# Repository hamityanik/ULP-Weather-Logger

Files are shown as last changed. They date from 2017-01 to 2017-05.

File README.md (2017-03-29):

# ULP Weather Logger
Yet another ESP8266 (ESP-03) based ultra low power wi-fi weather logger with 4 sensors

[Follow me on Twitter (@hamityanik)](https://twitter.com/hamityanik) (@hamityanik)

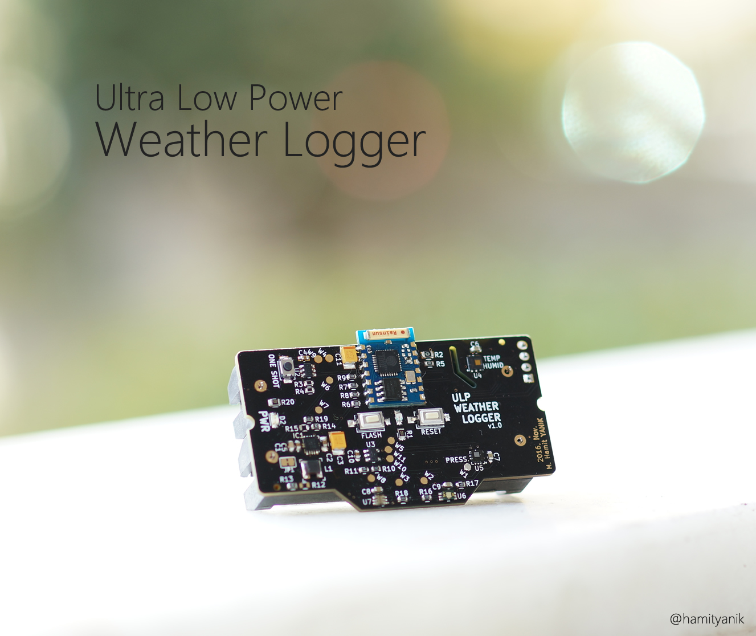
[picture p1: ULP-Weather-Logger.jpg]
Ultra Low Power Weather Logger


> **Features**

> - Working with two **AA** battery
> - Ultra low power consumption
> - **4 sensors and 6 measurements:**
>  - HDC1080 - Temperature & Humidity
>  - LPS25HB - Pressure
>  - VEML6070 - Ultraviolet Index
>  - TSL2561 - Ambient & Infrared
> - Built-in 3.3v Boost Converter
> - TPL5111 System Timer (20 mins update interval, can be customized via resistors)
> - Battery voltage monitor
> - UART port for programming & debugging 

## Blynk Integration
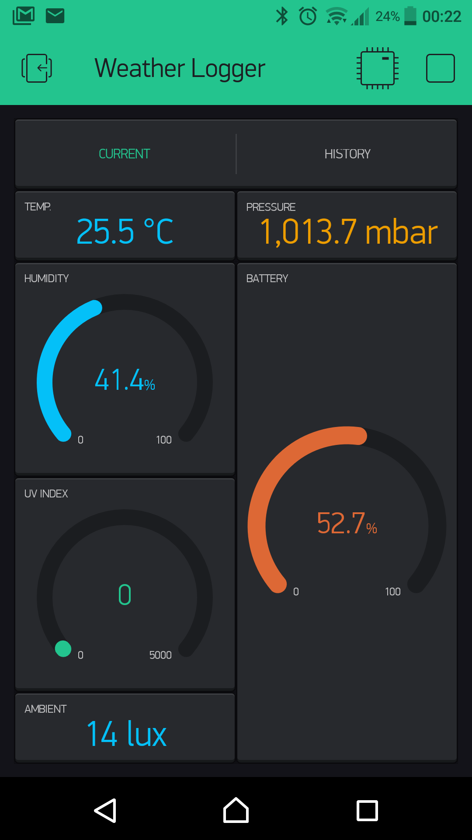
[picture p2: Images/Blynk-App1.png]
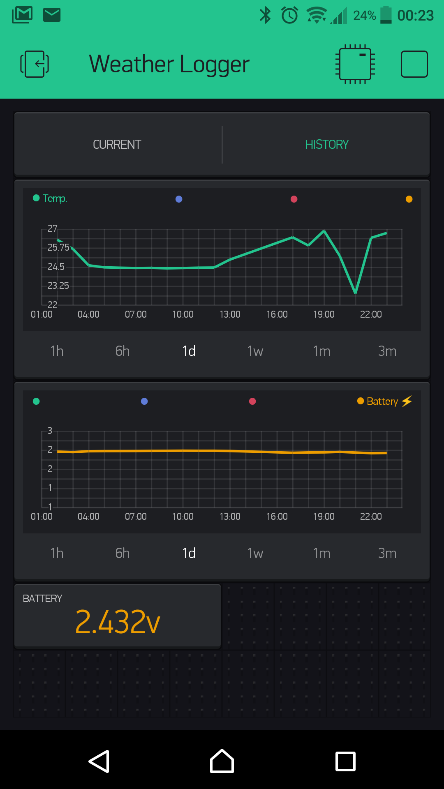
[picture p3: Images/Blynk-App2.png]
 

## How can you buy one?


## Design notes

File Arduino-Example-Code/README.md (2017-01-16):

# Example Arduino Code
-----

In **libraries** folder, there are optimized versions of sensor libraries. Use with caution.

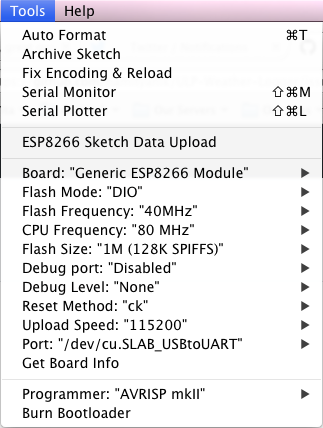
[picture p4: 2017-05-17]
Images/arduino_config.png

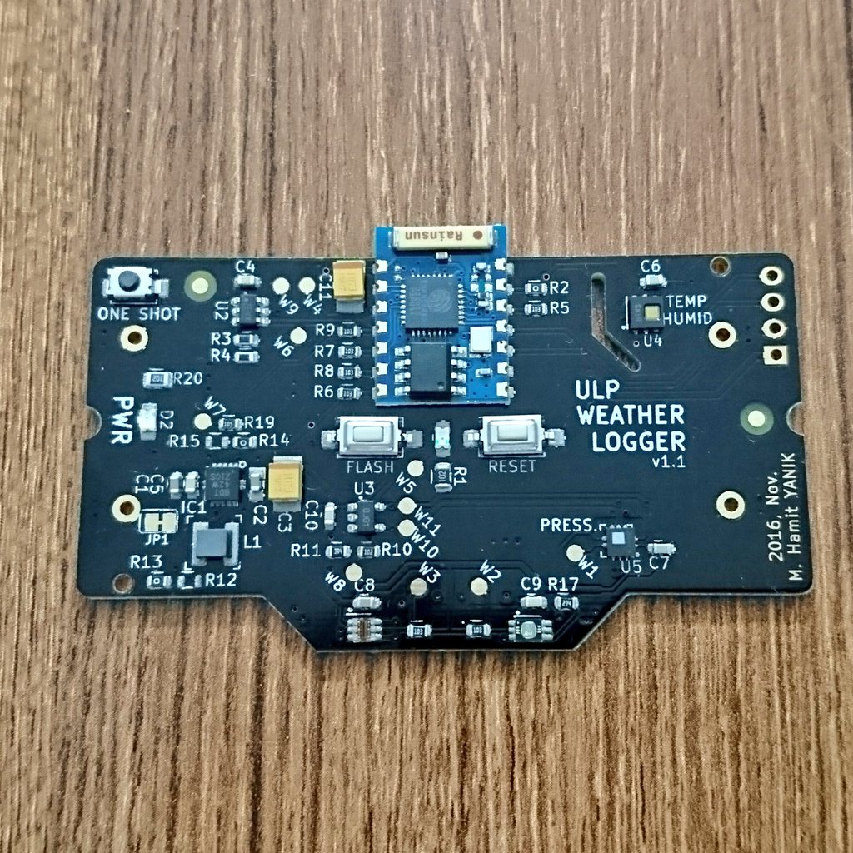
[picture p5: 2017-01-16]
Images/IMG_-c0ex6u.jpg

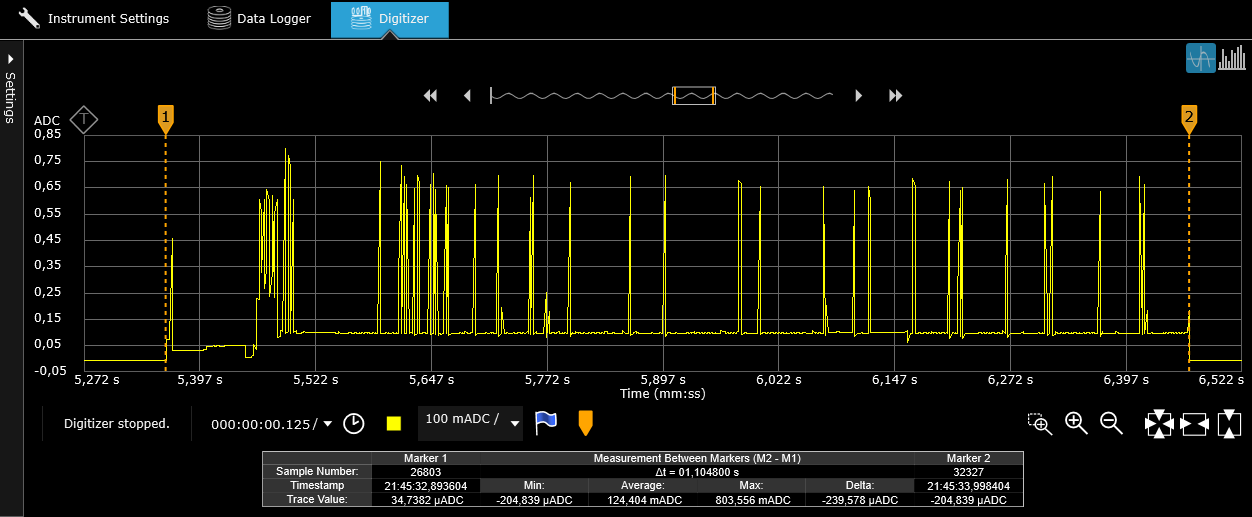
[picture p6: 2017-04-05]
Images/@2.5v.png

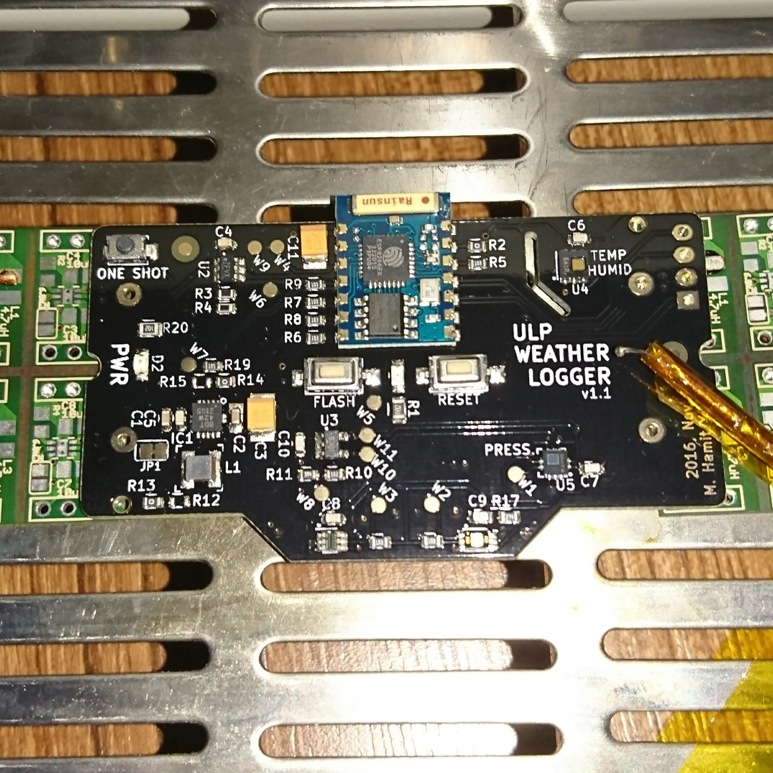
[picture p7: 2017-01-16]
Images/IMG_962an6.jpg

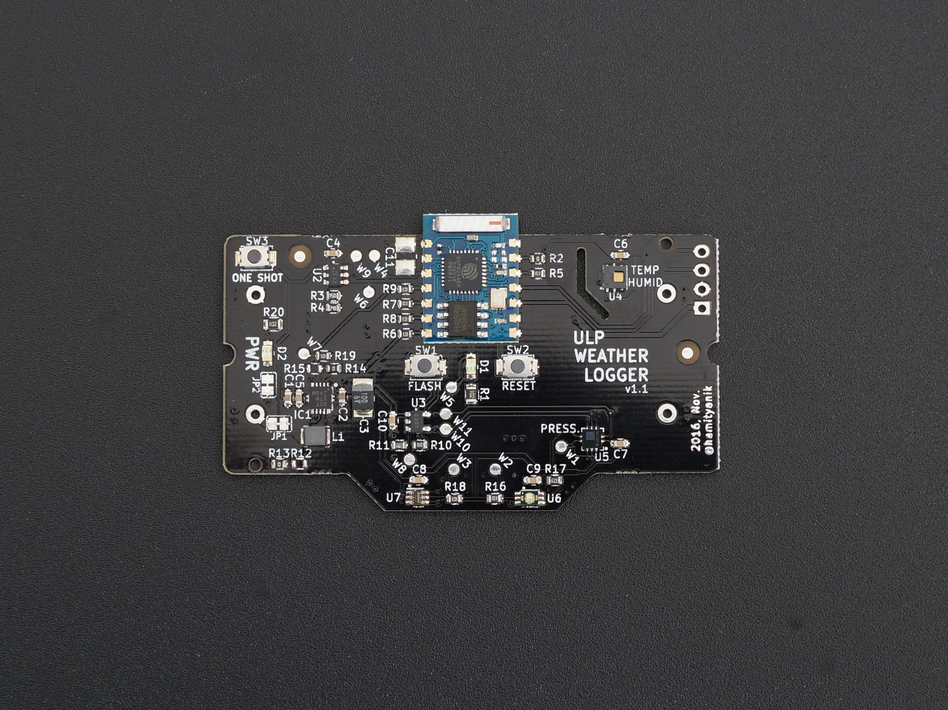
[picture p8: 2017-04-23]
Images/WL 1.jpg

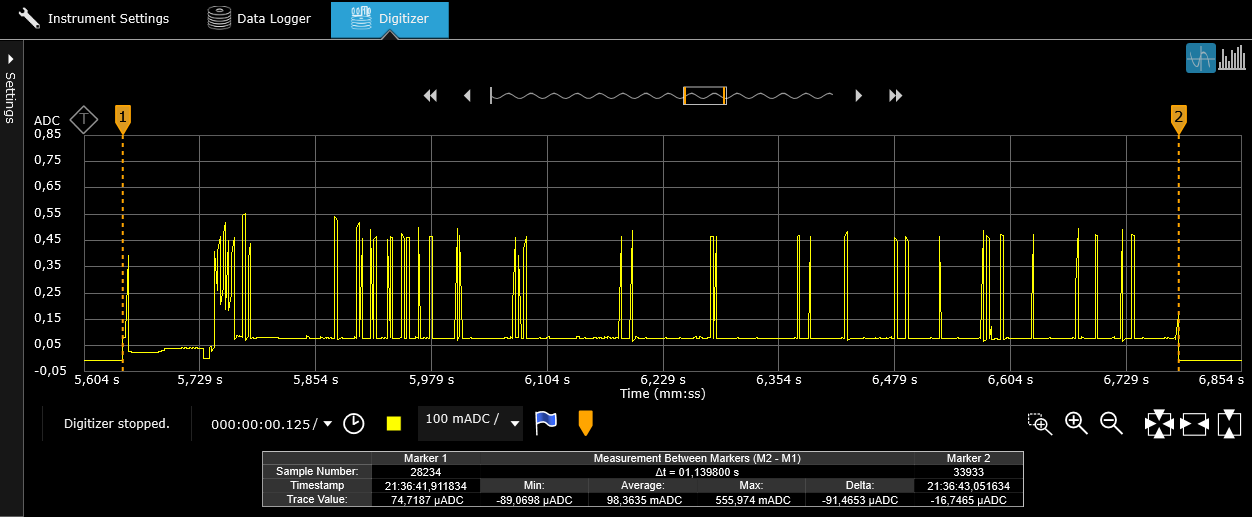
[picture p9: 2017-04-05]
Images/@3v.png

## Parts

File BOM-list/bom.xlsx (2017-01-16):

 |  |  |  |  | Board Qty: | 100
 |  |  |  |  | Total Cost: | $1607.98 |  |  |  | $1344.93 |  |  |  |  |  | $3472.30 |  |  |  |  |  | $1281.30 |  |  |  |  |  | $690.00 |  |  |  |  |  | $721.47 |  |  |  |  |  | $0.00
 |  |  |  |  | Unit Cost: | $16.08
Global Part Info |  |  |  |  |  |  | Digi-Key |  |  |  |  |  | Farnell |  |  |  |  |  | Mouser |  |  |  |  |  | Newark |  |  |  |  |  | Rs Components |  |  |  |  |  | Local
Refs | Value | Manf | Manf# | Qty | Unit$ | Ext$ | Avail | Purch | Unit$ | Ext$ | Cat# | Doc | Avail | Purch | Unit$ | Ext$ | Cat# | Doc | Avail | Purch | Unit$ | Ext$ | Cat# | Doc | Avail | Purch | Unit$ | Ext$ | Cat# | Doc | Avail | Purch | Unit$ | Ext$ | Cat# | Doc | Avail | Purch | Unit$ | Ext$ | Cat# | Doc
R10 | 1k | Yageo | RC0603FR-071KL | 100 | $0.003 | $0.30 | 9492159 |  | $0.01 | $0.52 | 311-1.00KHRCT-ND | Link (http://www.digikey.com/product-detail/en/yageo/RC0603FR-071KL/311-1.00KHRCT-ND/729790) | 160280 |  | $0.01 | $0.83 | 9238484 | Link (http://it.farnell.com/yageo-phycomp/rc0603fr-071kl/res-film-spesso-1k-1-0-1w-0603/dp/9238484) | 599743 |  | $0.003 | $0.30 | 603-RC0603FR-071KL | Link (http://www.mouser.com/Search/Refine.aspx?Keyword=RC0603FR-071KL%20Yageo) | 4140 |  | $0.01 | $0.60 | 68R0042 | Link (http://www.newark.com/yageo/rc0603fr-071kl/res-thick-film-1k-1-0-1w-0603/dp/68R0042)
D2 | PWR | Lite-On Inc. | LTST-C171KRKT | 100 | $0.12 | $11.83 | 143608 |  | $0.12 | $11.83 | 160-1427-1-ND | Link (http://www.digikey.com/product-detail/en/lite-on-inc/LTST-C171KRKT/160-1427-1-ND/386800) |  |  |  |  |  |  |  |  |  |  |  |  |  |  |  |  |  |  | 250 |  | $0.17 | $16.94 | 692-0941 | Link (http://it.rs-online.com/web/c/?searchTerm=LTST-C171KRKT%20Lite-On%20Inc.)
U6 | VEML6070 | Vishay Semiconductor Opto Division | VEML6070 | 100 | $1.25 | $125.00 | 3205 |  | $1.50 | $149.60 | VEML6070CT-ND | Link (http://www.digikey.com/product-detail/en/vishay-semiconductor-opto-division/VEML6070/VEML6070CT-ND/5171286) | 3617 |  | $1.43 | $142.94 | 2504137 | Link (http://it.farnell.com/vishay/veml6070/sensore-raggi-uv-5-5v-16bit-digitale/dp/2504137) |  |  |  |  |  |  | 1493 |  | $1.25 | $125.00 | 41Y9254 | Link (http://www.newark.com/vishay/veml6070/uv-light-sensor-355nm-i2c/dp/41Y9254)
L1 | 6.8uH | Murata Electronics | LQH32PN6R8NN0L | 100 | $0.24 | $23.51 | 5376 |  | $0.26 | $25.51 | 490-5339-1-ND | Link (http://www.digikey.com/product-detail/en/murata-electronics-north-america/LQH32PN6R8NN0L/490-5339-1-ND/2092212) |  |  |  |  |  |  | 1476 |  | $0.24 | $23.60 | 81-LQH32PN6R8NN0L | Link (http://www.mouser.com/Search/Refine.aspx?Keyword=LQH32PN6R8NN0L%20Murata%20Electronics) |  |  |  |  |  |  | 1660 |  | $0.24 | $23.51 | 786-6908 | Link (http://it.rs-online.com/web/c/?searchTerm=LQH32PN6R8NN0L%20Murata%20Electronics)
R3 | 140k | Yageo | RC0603FR-07140KL | 100 | $0.003 | $0.30 | 190971 |  | $0.01 | $0.52 | 311-140KHRCT-ND | Link (http://www.digikey.com/product-detail/en/yageo/RC0603FR-07140KL/311-140KHRCT-ND/729894) |  |  |  |  |  |  | 24121 |  | $0.003 | $0.30 | 603-RC0603FR-07140KL | Link (http://www.mouser.com/Search/Refine.aspx?Keyword=RC0603FR-07140KL%20Yageo) |  |  |  |  |  | Link (http://www.newark.com/webapp/wcs/stores/servlet/Search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)
R4 | 174k | Yageo | RC0603FR-07174KL | 100 | $0.003 | $0.30 | 171006 |  | $0.01 | $0.52 | 311-174KHRCT-ND | Link (http://www.digikey.com/product-detail/en/yageo/RC0603FR-07174KL/311-174KHRCT-ND/729932) |  |  |  |  |  |  | 61300 |  | $0.003 | $0.30 | 603-RC0603FR-07174KL | Link (http://www.mouser.com/Search/Refine.aspx?Keyword=RC0603FR-07174KL%20Yageo) |  |  |  |  |  | Link (http://www.newark.com/webapp/wcs/stores/servlet/Search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)
SW3 | M_DRV | C&K | PTS820 J15M SMTR LFS | 100 | $0.35 | $35.20 | 76752 |  | $0.35 | $35.20 | CKN10506CT-ND | Link (http://www.digikey.com/product-detail/en/c-k/PTS820-J15M-SMTR-LFS/CKN10506CT-ND/4176681) |  |  |  |  |  |  |  |  |  |  |  | Link (http://www.mouser.com/ProductDetail/CK-Components/PTS820-J15M-SMTR-LFS/)
BT1,BT2 | Battery | Keystone Electronics | 1015 | 200 | $1.72 | $344.00 |  |  |  |  |  |  |  |  |  |  |  |  | 121 |  | $1.72 | $344.00 | 534-1015 | Link (http://www.mouser.com/Search/Refine.aspx?Keyword=1015%20Keystone%20Electronics)
SW1,SW2 | FLASH,RESET | C&K | RS-282G05A3-SM RT | 200 | $0.55 | $110.00 | 52850 |  | $0.55 | $110.00 | CKN10384CT-ND | Link (http://www.digikey.com/product-detail/en/c-k/RS-282G05A3-SM-RT/CKN10384CT-ND/2747203) |  |  |  |  |  |  | 6708 |  | $0.55 | $110.00 | 611-RS-282G05A3-SMRT | Link (http://www.mouser.com/Search/Refine.aspx?Keyword=RS-282G05A3-SM%20RT%20C%26K)
U3 | MCP3021 | Microchip Technology | MCP3021A5T-E/OT | 100 | $0.81 | $81.00 | 21773 |  | $0.83 | $83.43 | MCP3021A5T-E/OTCT-ND | Link (http://www.digikey.com/product-detail/en/microchip-technology/MCP3021A5T-E-OT/MCP3021A5T-E-OTCT-ND/1979808) |  |  |  |  |  |  | 5652 |  | $0.81 | $81.00 | 579-MCP3021A5T-E/OT | Link (http://www.mouser.com/Search/Refine.aspx?Keyword=MCP3021A5T-E%2FOT%20Microchip%20Technology) |  |  |  |  |  |  | 16 |  | $0.94 | $94.23 | 738-6011 | Link (http://it.rs-online.com/web/p/adc-per-impieghi-generali/7386011/)
C4-C10 | 0.1uF | Murata Electronics | GRM188R71C104KA01D | 700 | $0.01 | $4.20 | 4352363 |  | $0.01 | $4.20 | 490-1532-1-ND | Link (http://www.digikey.com/product-detail/en/murata-electronics-north-america/GRM188R71C104KA01D/490-1532-1-ND/587771) | 34491 |  | $0.01 | $7.19 | 1828890 | Link (http://it.farnell.com/murata/grm188r71c104ka01d/condensatore-mlcc-x7r-100nf-16v/dp/1828890) | 945379 |  | $0.01 | $4.90 | 81-GRM39X104K16 | Link (http://www.mouser.com/Search/Refine.aspx?Keyword=GRM188R71C104KA01D%20Murata%20Electronics) | 8380 |  | $0.01 | $4.90 | 14T3312 | Link (http://www.newark.com/webapp/wcs/stores/servlet/Search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) |  |  |  |  |  | Link (http://it.rs-online.com/web/c/?searchTerm=GRM188R71C104KA01D%20Murata%20Electronics)
R5-R9,R16,R18 | 10k | Yageo | RC0603JR-0710KL | 700 | $0.002 | $1.40 | 3456780 |  | $0.00244 | $1.71 | 311-10KGRCT-ND | Link (http://www.digikey.com/product-detail/en/yageo/RC0603JR-0710KL/311-10KGRCT-ND/729647) | 31801 |  | $0.00487048 | $3.41 | 9233504 | Link (http://it.farnell.com/yageo-phycomp/rc0603jr-0710kl/res-film-spesso-10k-5-0-1w-0603/dp/9233504) | 802226 |  | $0.002 | $1.40 | 603-RC0603JR-0710KL | Link (http://www.mouser.com/Search/Refine.aspx?Keyword=RC0603JR-0710KL%20Yageo) | 10107 |  | $0.003 | $2.10 | 68R0144 | Link (http://www.newark.com/yageo/rc0603jr-0710kl/res-thick-film-10k-5-0-1w-0603/dp/68R0144)
R11 | 390k | Yageo | RC0603FR-07390KL | 100 | $0.003 | $0.30 | 101529 |  | $0.01 | $0.52 | 311-390KHRCT-ND | Link (http://www.digikey.com/product-detail/en/yageo/RC0603FR-07390KL/311-390KHRCT-ND/730146) | 6728 |  | $0.01 | $0.71 | 9238794 | Link (http://it.farnell.com/yageo-phycomp/rc0603fr-07390kl/res-film-spesso-390k-1-0-1w-0603/dp/9238794) | 61106 |  | $0.003 | $0.30 | 603-RC0603FR-07390KL | Link (http://www.mouser.com/Search/Refine.aspx?Keyword=RC0603FR-07390KL%20Yageo) | 3318 |  | $0.01 | $0.70 | 98K7407 | Link (http://www.newark.com/webapp/wcs/stores/servlet/Search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)
C1 | 10uF | Murata Electronics | GRM188R61A106KE69D | 100 | $0.05 | $4.98 | 66078 |  | $0.06 | $5.94 | 490-10474-1-ND | Link (http://www.digikey.com/product-detail/en/murata-electronics-north-america/GRM188R61A106KE69D/490-10474-1-ND/5026392) | 47360 |  | $0.06 | $5.69 | 2494233 | Link (http://it.farnell.com/murata/grm188r61a106ke69d/condensatore-mlcc-x5r-10uf-10v/dp/2494233) | 243070 |  | $0.06 | $5.50 | 81-GRM188R61A106KE9D | Link (http://www.mouser.com/ProductDetail/Murata-Electronics/GRM188R61A106KE69D/) |  |  |  |  |  |  | 1900 |  | $0.05 | $4.98 | 846-7293 | Link (http://it.rs-online.com/web/c/?searchTerm=GRM188R61A106KE69D%20Murata%20Electronics)
C3,C11 | 100uF | AVX Corporation | F930J107MBA | 200 | $0.26 | $52.68 | 41767 |  | $0.26 | $52.68 | 478-8156-1-ND | Link (http://www.digikey.com/product-detail/en/avx-corporation/F930J107MBA/478-8156-1-ND/4005661) |  |  |  |  |  |  |  |  |  |  |  | Link (http://www.mouser.com/Search/Refine.aspx?Keyword=F930J107MBA%20AVX%20Corporation) |  |  |  |  |  | Link (http://www.newark.com/webapp/wcs/stores/servlet/Search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)
U4 | HDC1080 | Texas Instruments | HDC1080DMBT | 100 | $2.42 | $242.00 | 6303 |  | $2.50 | $249.64 | 296-43864-1-ND | Link (http://www.digikey.com/product-detail/en/texas-instruments/HDC1080DMBT/296-43864-1-ND/5878615) | 299 |  | $4.12 | $411.87 | 2535017 | Link (http://it.farnell.com/texas-instruments/hdc1080dmbt/sensore-umid-temp-0-100-rh-wson/dp/2535017) | 21477 |  | $2.42 | $242.00 | 595-HDC1080DMBT | Link (http://www.mouser.com/ProductDetail/Texas-Instruments/HDC1080DMBT/) | 303 |  | $3.02 | $302.00 | 02AC3671 | Link (http://www.newark.com/webapp/wcs/stores/servlet/Search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)
R19 | 1M | Yageo | RC0603JR-071ML | 100 | $0.002 | $0.20 | 733465 |  | $0.004 | $0.40 | 311-1.0MGRCT-ND | Link (http://www.digikey.com/product-detail/en/yageo/RC0603JR-071ML/311-1.0MGRCT-ND/729625) | 9350 |  | $0.01 | $0.56 | 9233741 | Link (http://it.farnell.com/yageo-phycomp/rc0603jr-071ml/res-film-spesso-1m-5-0-1w-0603/dp/9233741) | 46107 |  | $0.002 | $0.20 | 603-RC0603JR-071ML | Link (http://www.mouser.com/Search/Refine.aspx?Keyword=RC0603JR-071ML%20Yageo) | 3051 |  | $0.004 | $0.40 | 68R0141 | Link (http://www.newark.com/yageo/rc0603jr-071ml/res-thick-film-1m-5-0-1w-0603/dp/68R0141)
U2 | TPL5111 | Texas Instruments | TPL5111DDCT | 100 | $0.64 | $64.30 | 3051 |  | $0.66 | $66.36 | 296-42621-1-ND | Link (http://www.digikey.com/product-detail/en/texas-instruments/TPL5111DDCT/296-42621-1-ND/5452146) | 292 |  | $0.92 | $91.69 | 2507126 | Link (http://it.farnell.com/texas-instruments/tpl5111ddct/timer-di-sistema-singolo-5-5v/dp/2507126) | 4021 |  | $0.64 | $64.30 | 595-TPL5111DDCT | Link (http://www.mouser.com/ProductDetail/Texas-Instruments/TPL5111DDCT/) | 265 |  | $0.71 | $71.30 | 68Y0736 | Link (http://www.newark.com/texas-instruments/tpl5111ddct/system-timer-single-5-5v-sot-23/dp/68Y0736)
D1 | Hearthbeat | Lite-On Inc. | LTST-C170KFKT | 100 | $0.12 | $11.83 | 5001 |  | $0.12 | $11.83 | 160-1413-1-ND | Link (http://www.digikey.com/product-detail/en/lite-on-inc/LTST-C170KFKT/160-1413-1-ND/386774)
R17 | 270k | Yageo | RC0603FR-07270KL | 100 | $0.003 | $0.30 | 391055 |  | $0.01 | $0.52 | 311-270KHRCT-ND | Link (http://www.digikey.com/product-detail/en/yageo/RC0603FR-07270KL/311-270KHRCT-ND/730051) | 20640 |  | $0.01 | $0.71 | 9238778 | Link (http://it.farnell.com/yageo-phycomp/rc0603fr-07270kl/res-film-spesso-270k-1-0-1w-0603/dp/9238778) | 67081 |  | $0.003 | $0.30 | 603-RC0603FR-07270KL | Link (http://www.mouser.com/Search/Refine.aspx?Keyword=RC0603FR-07270KL%20Yageo) | 6197 |  | $0.01 | $0.60 | 98K7388 | Link (http://www.newark.com/webapp/wcs/stores/servlet/Search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)
IC1 | TPS61025 | Texas Instruments | TPS61025DRCR | 100 | $1.20 | $119.64 | 3769 |  | $1.58 | $157.68 | 296-15844-1-ND | Link (http://www.digikey.com/product-detail/en/texas-instruments/TPS61025DRCR/296-15844-1-ND/600559) | 204 |  | $1.20 | $119.64 | 1703402 | Link (http://it.farnell.com/texas-instruments/tps61025drcr/ic-dc-dc-converter-voltage-reg/dp/1703402) | 1925 |  | $1.53 | $153.00 | 595-TPS61025DRCR | Link (http://www.mouser.com/Search/Refine.aspx?Keyword=TPS61025DRCR%20Texas%20Instruments) | 102 |  | $1.70 | $170.00 | 87H2896 | Link (http://www.newark.com/texas-instruments/tps61025drcr/synchronous-boost-converter-son/dp/87H2896) | 630 |  | $1.24 | $123.88 | 709-4683 | Link (http://it.rs-online.com/web/c/?searchTerm=TPS61025DRCR%20Texas%20Instruments)
U7 | TSL2561 | AMS-TAOS USA Inc. | TSL2561FN | 100 | $1.30 | $129.80 | 15322 |  | $1.30 | $129.80 | TSL2561-FNCT-ND | Link (http://www.digikey.com/product-detail/en/ams-taos-usa-inc/TSL2561FN/TSL2561-FNCT-ND/3095298) | 35 |  | $26.76 | $2675.59 | 1871853 | Link (http://it.farnell.com/webapp/wcs/stores/servlet/Search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.) |  |  |  |  |  | Link (http://www.mouser.com/Search/Refine.aspx?Keyword=TSL2561FN%20AMS-TAOS%20USA%20Inc.)
R1,R20 | 1k | Yageo | RC0805JR-071KL | 200 | $0.01 | $1.00 | 1316006 |  | $0.01 | $1.32 | 311-1.0KARCT-ND | Link (http://www.digikey.com/product-detail/en/yageo/RC0805JR-071KL/311-1.0KARCT-ND/731165) | 69660 |  | $0.01 | $1.97 | 9234004 | Link (http://it.farnell.com/yageo-phycomp/rc0805jr-071kl/res-film-spesso-1k-5-0-125w-0805/dp/9234004) | 221237 |  | $0.01 | $1.00 | 603-RC0805JR-071KL | Link (http://www.mouser.com/Search/Refine.aspx?Keyword=RC0805JR-071KL%20Yageo) | 819 |  | $0.01 | $1.40 | 68R0253 | Link (http://www.newark.com/yageo/rc0805jr-071kl/res-thick-film-1k-5-0-125w-0805/dp/68R0253)
U1 | ESP8266-ESP-03 | Ai-Thinker | ESP-03 | 100 | $0.00 | $0.00
C2 | 2.2uF | Murata Electronics | GRM21BR71A225KA01L | 100 | $0.04 | $4.30 | 61085 |  | $0.05 | $5.23 | 490-1696-1-ND | Link (http://www.digikey.com/product-detail/en/murata-electronics-north-america/GRM21BR71A225KA01L/490-1696-1-ND/587402) | 7646 |  | $0.07 | $6.84 | 1828923 | Link (http://it.farnell.com/murata/grm21br71a225ka01l/condensatore-mlcc-x7r-2-2uf-10v/dp/1828923) | 86773 |  | $0.04 | $4.30 | 81-GRM21BR71A225KA01 | Link (http://www.mouser.com/Search/Refine.aspx?Keyword=GRM21BR71A225KA01L%20Murata%20Electronics) | 5591 |  | $0.10 | $10.10 | 14T3346 | Link (http://www.newark.com/webapp/wcs/stores/servlet/Search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) | 123 |  | $1.99 | $199.05 | 106-757 | Link (http://it.rs-online.com/web/c/?searchTerm=GRM21BR71A225KA01L%20Murata%20Electronics)
U5 | LPS25HB | STMicroelectronics | LPS25HBTR | 100 | $2.39 | $239.01 | 7273 |  | $2.39 | $239.01 | 497-15070-1-ND | Link (http://www.digikey.com/product-detail/en/stmicroelectronics/LPS25HBTR/497-15070-1-ND/5043076) |  |  |  |  |  |  | 9099 |  | $2.44 | $244.00 | 511-LPS25HBTR | Link (http://www.mouser.com/Search/Refine.aspx?Keyword=LPS25HBTR%20STMicroelectronics) |  |  |  |  |  | Link (http://www.newark.com/webapp/wcs/stores/servlet/Search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) | 52 |  | $2.59 | $258.88 | 110-6550 | Link (http://it.rs-online.com/web/c/?searchTerm=LPS25HBTR%20STMicroelectronics)
R2,R13,R14 | 0R | Yageo | RC0603JR-070RL | 300 | $0.002 | $0.60 | 7872620 |  | $0.0032 | $0.96 | 311-0.0GRCT-ND | Link (http://www.digikey.com/product-detail/en/yageo/RC0603JR-070RL/311-0.0GRCT-ND/729622) | 84473 |  | $0.01 | $2.67 | 9233130 | Link (http://it.farnell.com/yageo-phycomp/rc0603jr-070rl/res-film-spesso-0r-5-0-1w-0603/dp/9233130) | 1314295 |  | $0.002 | $0.60 | 603-RC0603JR-070RL | Link (http://www.mouser.com/Search/Refine.aspx?Keyword=RC0603JR-070RL%20Yageo) | 5625 |  | $0.003 | $0.90 | 68R0136 | Link (http://www.newark.com/yageo/rc0603jr-070rl/res-thick-film-0r-0-1w-0603/dp/68R0136)

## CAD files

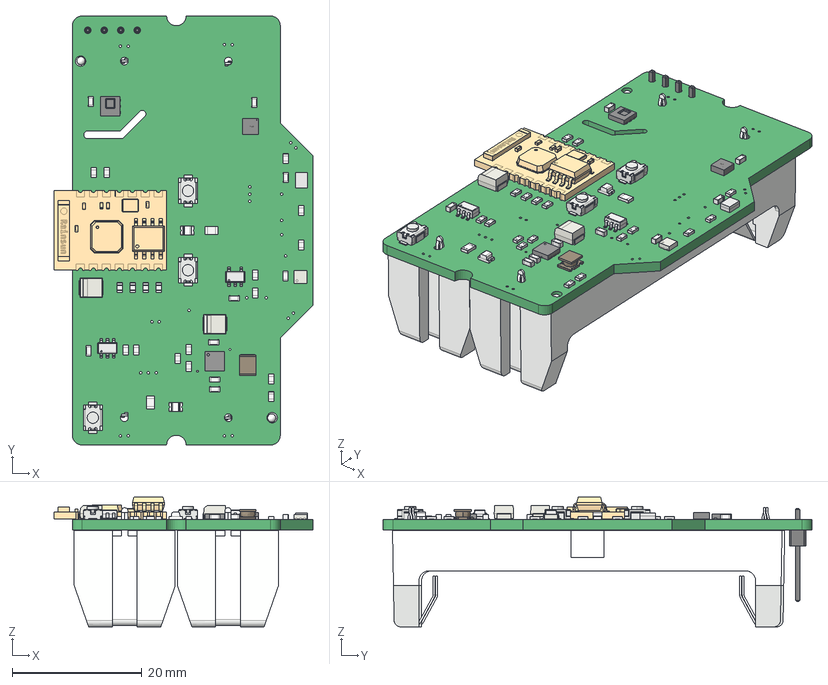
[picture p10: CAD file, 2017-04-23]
3D-CAD-files/board.FCStd
39.8 x 66.0 x 20.0 mm
Pcb
LPS25H_
TI_DRC_S-PVSON-N10_
r_0603_h078_
Tantalum_B_3528H21_
PinHeader_Straight_1x04x254mm_
r_0805_h078_
r_0603_h078_001
r_0603_h078_002
r_0603_h078_003
r_0603_h078_004
r_0603_h078_005
r_0603_h078_006
r_0603_h078_007
r_0603_h078_008
r_0603_h078_009
r_0603_h078_010
r_0603_h078_011
r_0603_h078_012
r_0603_h078_013
r_0603_h078_014
r_0603_h078_015
SOT-23-6_
Tantalum_B_3528H21_001
r_0603_h078_016
LED_0805_
r_0805_h078_001
dfn6_2x2_p065_
r_0603_h078_017
Keystone_1015_Holder_Battery_AA_
Keystone_1015_Holder_Battery_AA_001
ESP-03_
LED_0805_001
Tact_Switch_Top_PTS820_
Tact_Switch_Top_PTS820_001
Tact_Switch_Top_PTS820_002
LQH32PN_
c_0603_h078_
c_0603_h078_001
c_0603_h078_002
c_0603_h078_003
c_0603_h078_004
c_0603_h078_005
c_0603_h078_006
c_0603_h078_007
c_0603_h078_008

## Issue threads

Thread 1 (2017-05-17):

how to flash?

itzik16, 2017-05-17:
Hey mate Ive bought the board from tindie and having trouble to upload the firmware onto it
I've downloaded the additional included github libraries and blynk libraries and added ESP8266 boards  to the IDE using that link

> http://arduino.esp8266.com/versions/2.3.0/package_esp8266com_index.json

I have chose the ESP866 generic board with all the defualt setting and fail to flash I also uncommented the debug line and still nothing seem to happen. Can you please help, and show me your configuration and how to configure it properly.
It compiles but doesn't flash.
I used 3 different UART to USB just to make sure it wasnt the issue
Please help, Thanks In advance.

hamityanik, 2017-05-17:
Hello,

Did you read "How to program?" section on product description on Tindie?

https://www.tindie.com/products/iohippo/ulp-weather-logger-with-esp8266-wifi-iot/

Make sure your UART connection, GND to GND, TX to RX, RX to TX, and also USBtoUART bridge logic levels. It must be 3.3v.

Then, to enter bootload mode:
Press FLASH button and without releasing it, press and release ONE SHOT button, PWR LED will lights up. Release FLASH button. At this state, you are able to upload your sketch.

Arduino IDE configuration:
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

hamityanik, 2018-04-27:
Which USB to UART adapter you are using?

larskotthoff, 2018-04-27:
This one: https://www.amazon.com/gp/product/B01LRVQIFQ/

hamityanik, 2018-04-28:
Would you share Arduino IDE's tools menu screenshot?

larskotthoff, 2018-04-28:
Sure, attached. The port is /dev/ttyUSB0, I didn't attach the adapter so it doesn't show up.

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

hamityanik, 2018-04-30:
If device is ON, you can enter bootload mode by:
Press and hold Flash button, press and release Reset button, release Flash button.

If device is OFF:
Press and hold Flash button, press and release ONE SHOT button, release Flash button.

Then try uploading you sketch with these settings.

larskotthoff, 2018-04-30:
Thanks, I finally got it to work. I had connected RX to RX and TX to TX, but it turns out that it wanted RX connected to TX and TX to RX (maybe something mislabeled?). Working now.

hamityanik, 2018-04-30:
Good to hear that. :)

Closed 2018-04-30.

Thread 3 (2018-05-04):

Operation without battery?

larskotthoff, 2018-05-04:
I'm trying to run the logger connected to power using the 3.3V and ground pins, without batteries. It pushes data when connected to power, but doesn't update after the initial push. Is there anything I can change to make that happen?

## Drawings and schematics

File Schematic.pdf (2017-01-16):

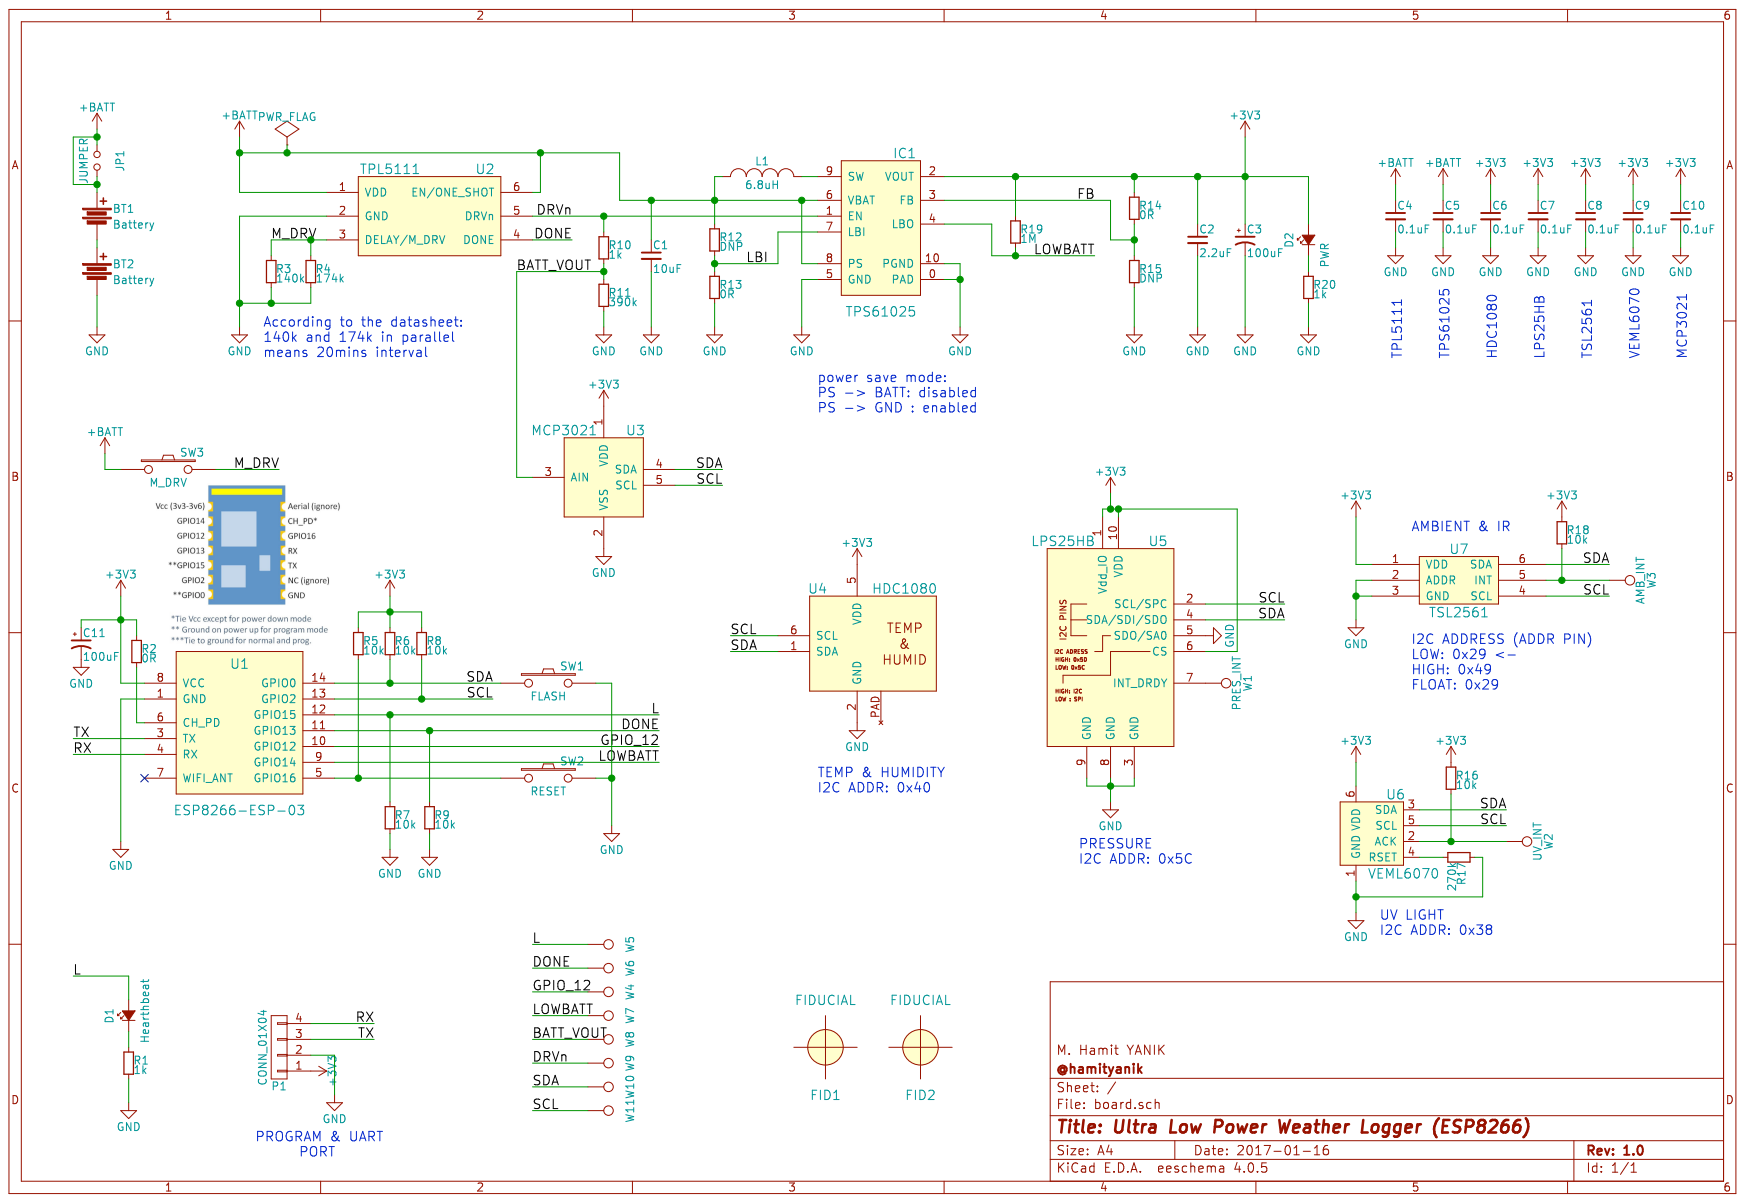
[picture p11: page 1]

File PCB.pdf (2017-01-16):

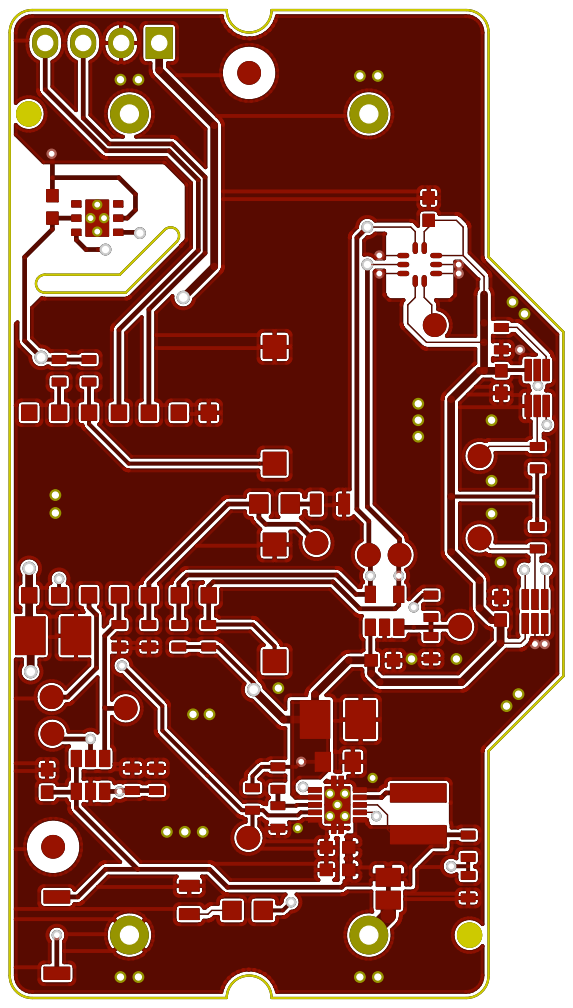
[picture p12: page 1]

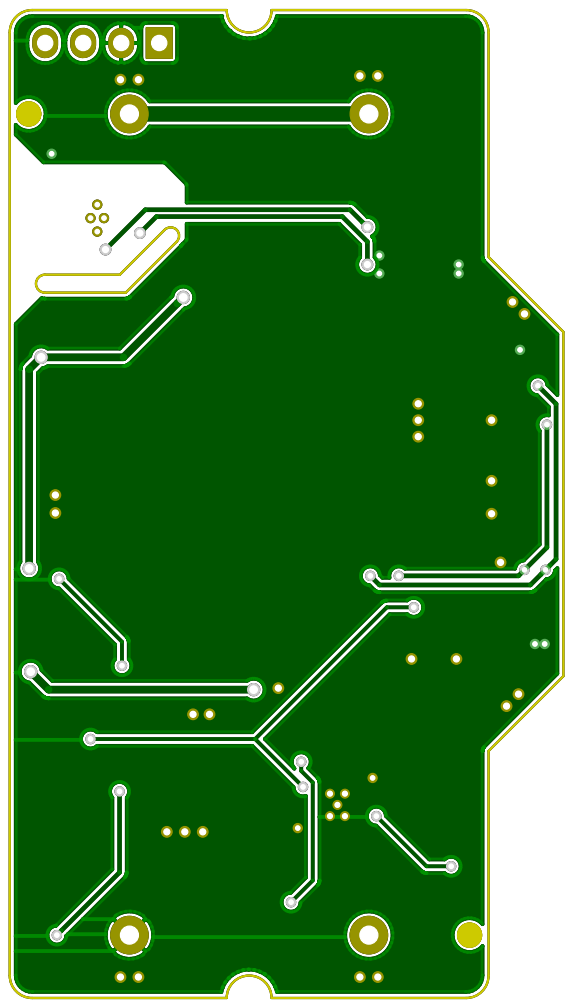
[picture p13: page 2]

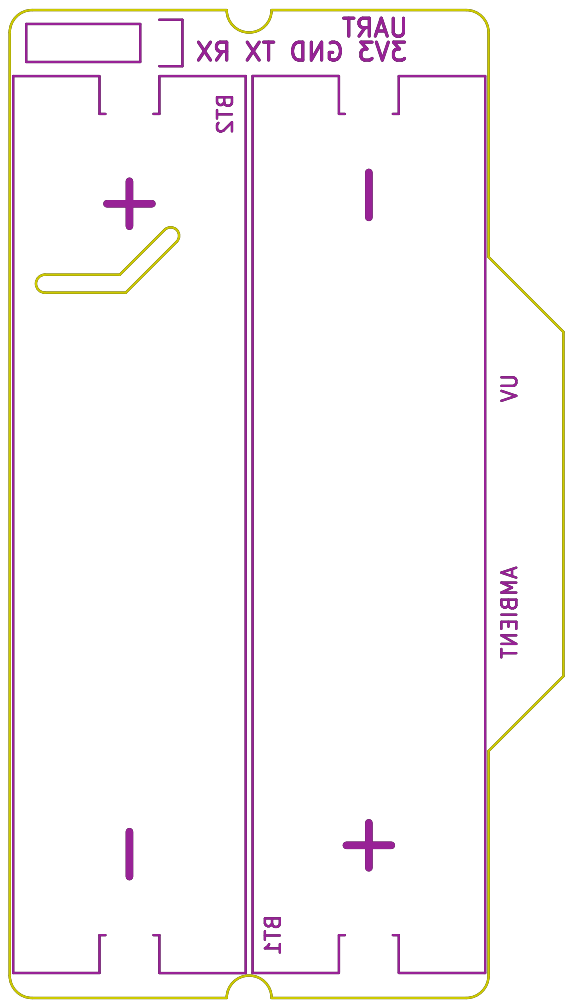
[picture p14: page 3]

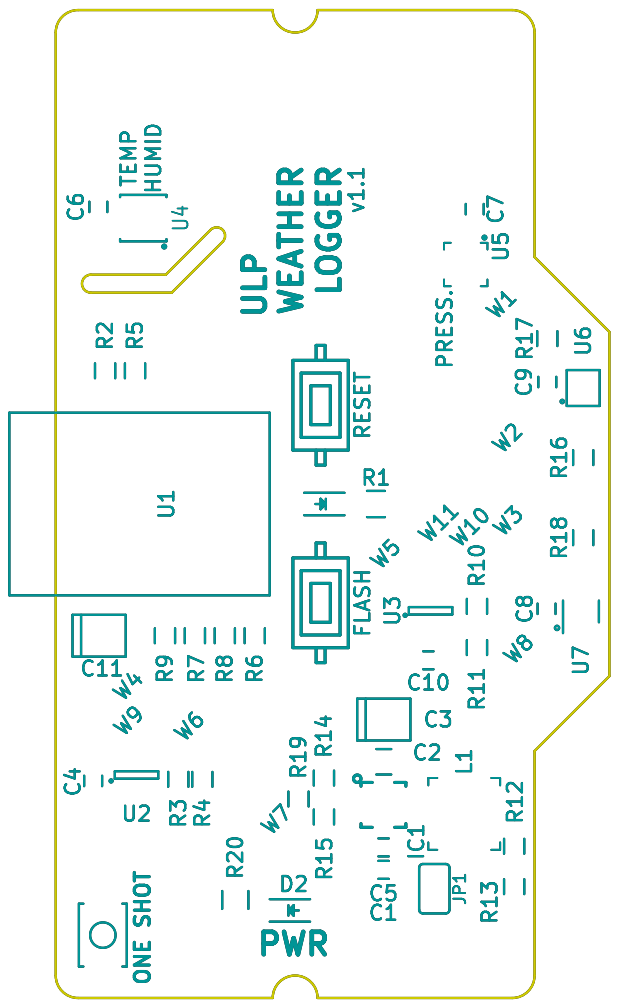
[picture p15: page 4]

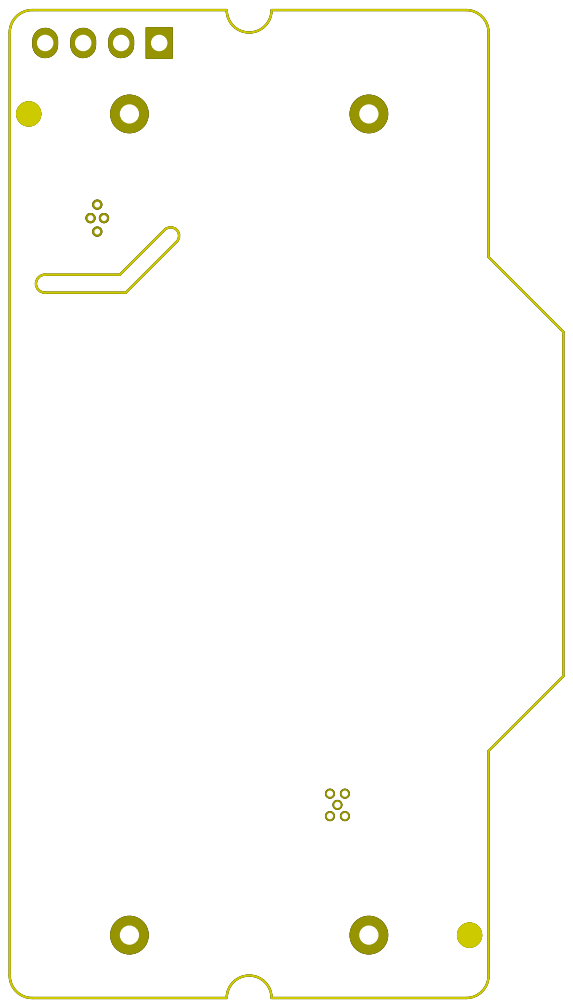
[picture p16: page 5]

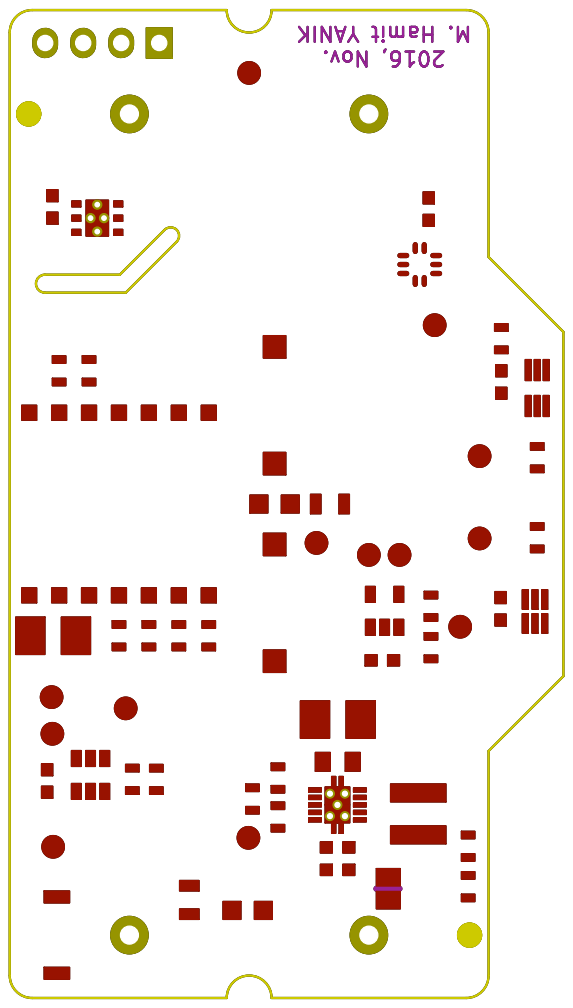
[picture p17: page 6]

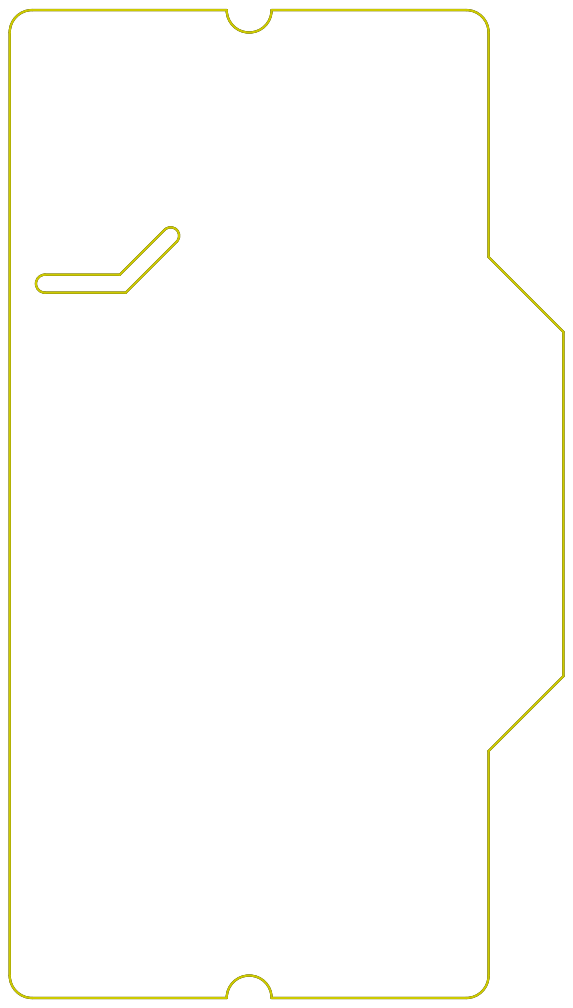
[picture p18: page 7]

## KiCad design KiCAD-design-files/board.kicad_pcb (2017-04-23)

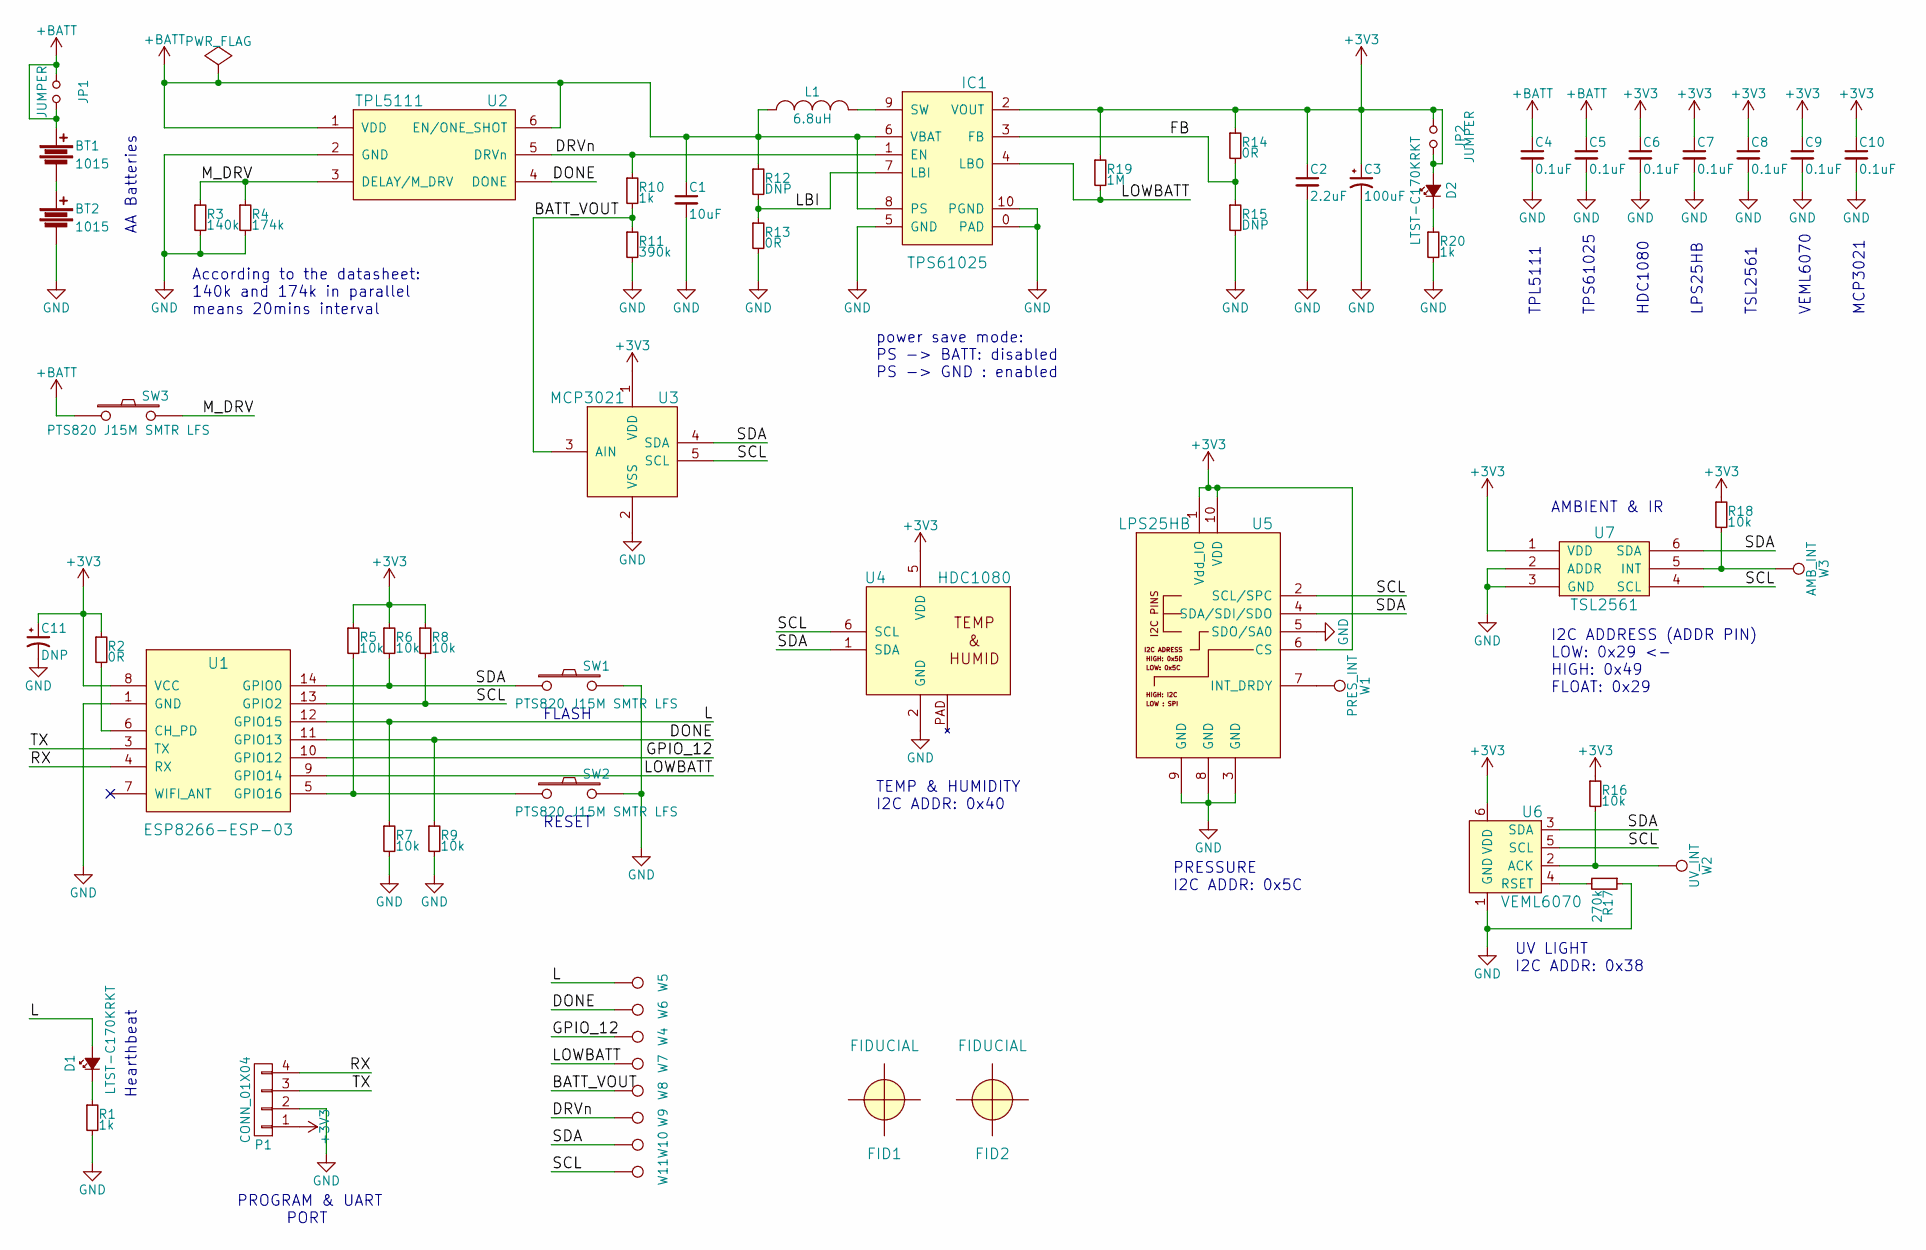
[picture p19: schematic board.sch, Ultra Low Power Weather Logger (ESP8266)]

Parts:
BT1, BT2: 1015; Keystone_1015_Holder_Battery_AA
C1: 10uF; C_0603
C2: 2.2uF; C_0603
C3: 100uF; TantalC_SizeB_EIA-3528_Reflow
C4, C5, C6, C7, C8, C9, C10: 0.1uF; C_0603
C11: DNP; TantalC_SizeB_EIA-3528_Reflow
D1, D2: LTST-C170KRKT; LED_0805
FID1, FID2: FIDUCIAL; Fiducial
IC1: TPS61025; TI_DRC_S-PVSON-N10
JP1, JP2: JUMPER; SJ_OPEN
L1: 6.8uH; Inductor_1210
P1: CONN_01X04; Pin_Header_Straight_1x04
R1, R20: 1k; R_0805
R2, R13, R14: 0R; R_0603
R3: 140k; R_0603
R4: 174k; R_0603
R5, R6, R7, R8, R9, R16, R18: 10k; R_0603
R10: 1k; R_0603
R11: 390k; R_0603
R12, R15: DNP; R_0603
R17: 270k; R_0603
R19: 1M; R_0603
SW1, SW2, SW3: PTS820 J15M SMTR LFS; Tact_Switch_Top_PTS820
U1: ESP8266-ESP-03
U2: TPL5111; SOT-23-6
U3: MCP3021; SOT-23-5
U4: HDC1080; WSON-6-PAD
U5: LPS25HB; ST_LPS25HB
U6: VEML6070; OPLGA6
U7: TSL2561; WDFN-6_2x2mm_Pitch0.65mm
W1: PRES_INT; Measurement_Point_Round-SMD-Pad_Small
W2: UV_INT; Measurement_Point_Round-SMD-Pad_Small
W3: AMB_INT; Measurement_Point_Round-SMD-Pad_Small
W4: GPIO_12; Measurement_Point_Round-SMD-Pad_Small
W5: L; Measurement_Point_Round-SMD-Pad_Small
W6: DONE; Measurement_Point_Round-SMD-Pad_Small
W7: LOWBATT; Measurement_Point_Round-SMD-Pad_Small
W8: BATT_VOUT; Measurement_Point_Round-SMD-Pad_Small
W9: DRVn; Measurement_Point_Round-SMD-Pad_Small
W10: SDA; Measurement_Point_Round-SMD-Pad_Small
W11: SCL; Measurement_Point_Round-SMD-Pad_Small

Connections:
+3V3: C2.1, C3.1, C6.1, C7.1, C8.1, C9.1, C10.1, C11.1, D2.2 (A), IC1.2 (VOUT), JP2.1, JP2.2, P1.1, R2.1, R5.1, R6.1, R8.1, R14.1, R16.1, R18.1, R19.1, U1.8 (VCC), U3.1 (VDD), U4.5 (VDD), U5.1 (Vdd_IO), U5.6 (CS), U5.10 (VDD), U6.6 (VDD), U7.1 (VDD)
+BATT: BT1.1, C1.1, C4.1, C5.1, IC1.6 (VBAT), IC1.8 (PS), JP1.1, JP1.2, L1.1, R12.1, SW3.1, U2.1 (VDD), U2.6 (EN/ONE_SHOT)
/BATT_VOUT: R10.2, R11.1, U3.3 (AIN), W8.1
/DONE: R9.1, U1.11 (GPIO13), U2.4 (DONE), W6.1
/DRVn: IC1.1 (EN), R10.1, U2.5 (DRVn), W9.1
/FB: IC1.3 (FB), R14.2, R15.1
/GPIO_12: U1.10 (GPIO12), W4.1
/L: D1.2 (A), R7.1, U1.12 (GPIO15), W5.1
/LBI: IC1.7 (LBI), R12.2, R13.1
/LOWBATT: IC1.4 (LBO), R19.2, U1.9 (GPIO14), W7.1
/M_DRV: R3.1, R4.1, SW3.2, U2.3 (DELAY/M_DRV)
/RX: P1.4, U1.4 (RX)
/SCL: R8.2, U1.13 (GPIO2), U3.5 (SCL), U4.6 (SCL), U5.2 (SCL/SPC), U6.5 (SCL), U7.4 (SCL), W11.1
/SDA: R6.2, SW1.1, U1.14 (GPIO0), U3.4 (SDA), U4.1 (SDA), U5.4 (SDA/SDI/SDO), U6.3 (SDA), U7.6 (SDA), W10.1
/TX: P1.3, U1.3 (TX)
GND: BT2.2, C1.2, C2.2, C3.2, C4.2, C5.2, C6.2, C7.2, C8.2, C9.2, C10.2, C11.2, IC1.0 (PAD), IC1.5 (GND), IC1.10 (PGND), P1.2, R1.2, R3.2, R4.2, R7.2, R9.2, R11.2, R13.2, R15.2, R17.1, R20.2, SW1.2, SW2.2, U1.1 (GND), U2.2 (GND), U3.2 (VSS), U4.2 (GND), U5.3 (GND), U5.5 (SDO/SA0), U5.8 (GND), U5.9 (GND), U6.1 (GND), U7.2 (ADDR), U7.3 (GND)
unnamed: BT1.2, BT2.1
unnamed: D1.1 (K), R1.1
unnamed: D2.1 (K), R20.1
unnamed: IC1.9 (SW), L1.2
unnamed: R2.2, U1.6 (CH_PD)
unnamed: R5.2, SW2.1, U1.5 (GPIO16)
unnamed: R16.2, U6.2 (ACK), W2.1
unnamed: R17.2, U6.4 (RSET)
unnamed: R18.2, U7.5 (INT), W3.1
unnamed: U5.7 (INT_DRDY), W1.1

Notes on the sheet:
power save mode: PS -> BATT: disabled PS -> GND : enabled
According to the datasheet: 140k and 174k in parallel means 20mins interval
HDC1080
TPS61025
TPL5111
LPS25HB
TSL2561
I2C ADDRESS (ADDR PIN) LOW: 0x29 <- HIGH: 0x49 FLOAT: 0x29
VEML6070
PRESSURE I2C ADDR: 0x5C
UV LIGHT I2C ADDR: 0x38
AMBIENT & IR
PROGRAM & UART PORT
TEMP & HUMIDITY I2C ADDR: 0x40
MCP3021
FLASH
RESET
Hearthbeat
AA Batteries

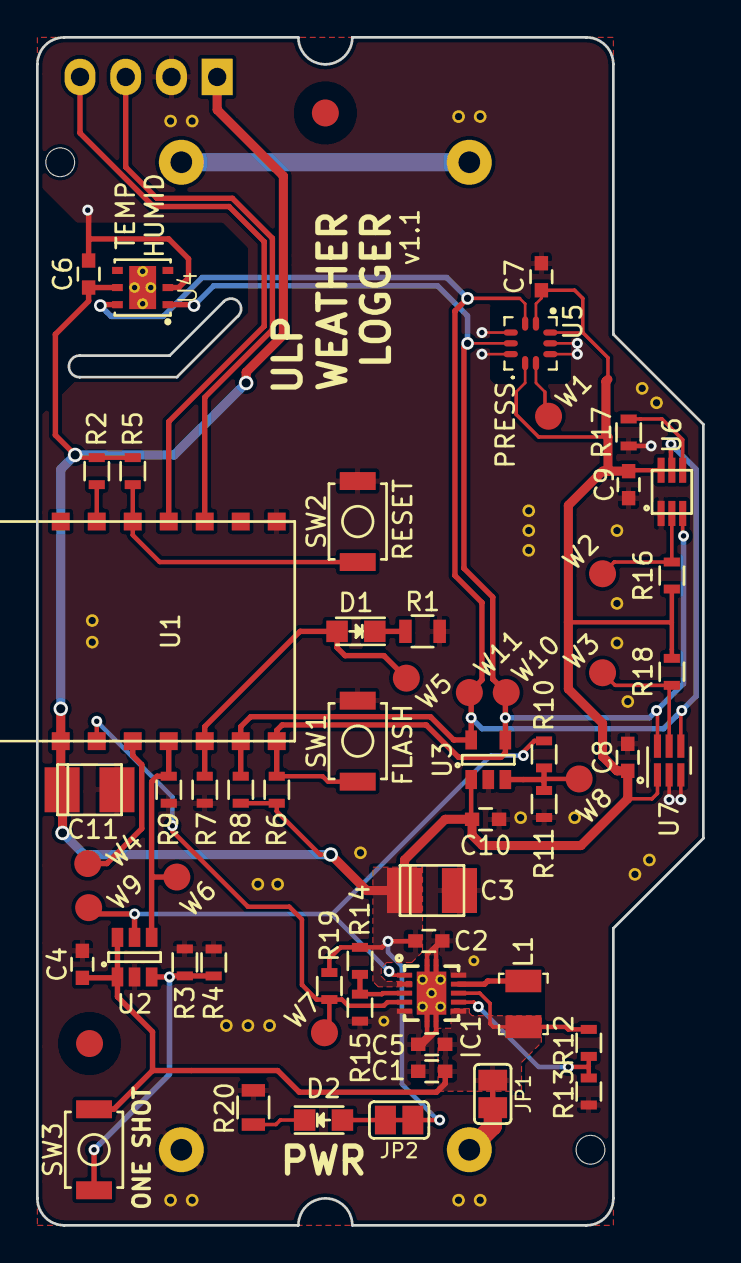
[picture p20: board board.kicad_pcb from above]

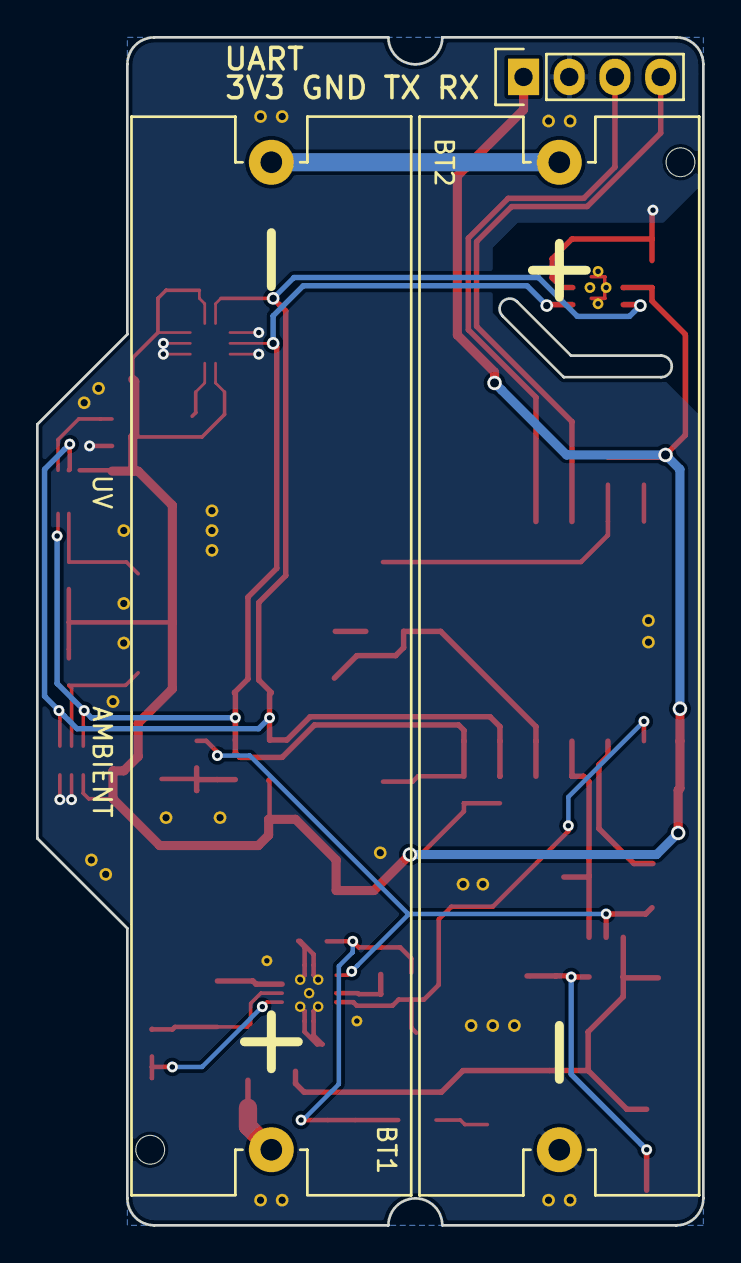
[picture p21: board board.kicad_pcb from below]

Board: 2 copper layers, 37.0 x 66.0 mm, 63 parts (3 on the bottom side), 26 nets.

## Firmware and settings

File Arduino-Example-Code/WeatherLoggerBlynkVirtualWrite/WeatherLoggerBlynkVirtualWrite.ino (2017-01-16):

/*
 * Ultra Low Power Weather Logger
 * Arduino Blynk example code
 *
 * Created: 15/01/2017 11:45:26
 *  Author: M. Hamit YANIK
 *          @hamityanik
 */

//#define DEBUG 1 // uncomment here for debugging through Serial

#ifdef DEBUG
#define BLYNK_PRINT Serial    // Comment this out to disable prints and save space
#define BLYNK_DEBUG 1
#endif

#define BLYNK_NO_BUILTIN //disable built-in analog and digital operations.
#define BLYNK_NO_INFO    //disable providing info about device to the server. (saving time)

#include <ESP8266WiFi.h>
#include <BlynkSimpleEsp8266.h>
#include "MCP3021.h"
#include <HDC1080.h>
#include <LPS25H.h>
#include "Adafruit_VEML6070.h"
#include "TSL2561.h"

const char* auth = "YOUR_BLYNK_AUTH_TOKEN";
const char* ssid = "SSID";
const char* password = "PASS";
const uint8_t node = 2;

const uint8_t status_led_pin  = 15;
const uint8_t done_pin = 13;

const uint8_t sda = 0;
const uint8_t scl = 2;

const uint8_t mcp3021_id = 5; // mcp3021a5t
float battery_volts = 0.0;

float temp = 0.0;
float humidity = 0.0;

float pressure = 0.0;
float temp2 = 0.0;

uint32_t uvIndex = 0;

uint32_t visible = 0, full = 0, infrared = 0;
uint32_t lux = 0;

uint64_t luminosity = 0;

float battery_percent = 0.0;

const uint8_t samples = 3;

/*
 * Sensor definitions
 */
MCP3021 battery;
HDC1080 tempHumid;
LPS25H press;
Adafruit_VEML6070 uv;
TSL2561 ambient(TSL2561_ADDR_LOW);

IPAddress ip(192, 168, 1, 77); // these 5 lines for a fix IP-address
IPAddress dns1(8, 8, 8, 8);
IPAddress dns2(8, 8, 4, 4);
IPAddress gateway(192, 168, 1, 1);
IPAddress subnet(255, 255, 255, 0);

// Mac address and channel information recommended for fast wifi connection
uint8_t router_mac[6] = { 0xXX, 0xXX, 0xXX, 0xXX, 0xXX, 0xXX }; // Your router's wifi mac address
uint8_t router_channel = 10; // Your router's wifi channel


IPAddress blynk_server_ip(188,166,206,43); // blynk-cloud.com IP is 188.166.206.43
                                           // providing IP address here for fast connection
                                           // to Blynk server without DNS resolution

unsigned long millisAtStart = 0;

void setup(void){
  millisAtStart = millis();

  //pinMode(led, OUTPUT);
  //digitalWrite(status_led_pin, 1);

  pinMode(done_pin, OUTPUT);

#ifdef DEBUG
  Serial.begin(115200);
  Serial.println("");
#endif

  WiFi.config(ip, gateway, subnet, dns1, dns2);
  WiFi.begin(ssid, password, router_channel, router_mac);

  Wire.begin(sda, scl);

  uv.begin(VEML6070_1_T);
  battery.begin();
  tempHumid.begin(0x40);
  press.begin();
  ambient.begin();

  // You can change the gain on the fly, to adapt to brighter/dimmer light situations
  ambient.setGain(TSL2561_GAIN_0X);         // set no gain (for bright situtations)
  //ambient.setGain(TSL2561_GAIN_16X);      // set 16x gain (for dim situations)

  // Changing the integration time gives you a longer time over which to sense light
  // longer timelines are slower, but are good in very low light situtations!
  ambient.setTiming(TSL2561_INTEGRATIONTIME_13MS);  // shortest integration time (bright light)
  //ambient.setTiming(TSL2561_INTEGRATIONTIME_101MS);  // medium integration time (medium light)
  //ambient.setTiming(TSL2561_INTEGRATIONTIME_402MS);  // longest integration time (dim light)

  // Wait for connection
  while (WiFi.status() != WL_CONNECTED) {
    unsigned long wl_millis = millis();

    if( wl_millis > 1200 ) {
      // shutdown immediately if wifi connection takes too long
      // power save if wifi modem is not reachable
      wl_shutdown();
    }

    delay(20);

#ifdef DEBUG
    Serial.print(".");
#endif
  }

#ifdef DEBUG
  Serial.print("\nConnected to ");
  Serial.println(ssid);
  Serial.print("IP address: ");
  Serial.println(WiFi.localIP());
#endif

  Blynk.config(auth, blynk_server_ip);

  while( Blynk.connect() == false ) {
#ifdef DEBUG
    Serial.print(".");
#endif
  }

#ifdef DEBUG
  Serial.println("Connected to Blynk server");
#endif
}

void loop(void) {
  post();
}

void post(void){
  for(int i=0; i<samples; i++) {
    humidity += tempHumid.readHumidity();
    temp     += tempHumid.readTemperature();
    pressure += press.readPressure();
    uvIndex  += uv.readUV();
    battery_volts += battery.read(mcp3021_id, 3.3);
  }

  battery_volts /= samples;
  humidity /= samples;
  temp     /= samples;
  pressure /= samples;
  uvIndex  /= samples;

  // barometrics pressure sensor's temperature reading
  temp2 = press.readTemperature();


  //visible = ambient.getLuminosity(TSL2561_VISIBLE);
  //full = ambient.getLuminosity(TSL2561_FULLSPECTRUM);
  //infrared = ambient.getLuminosity(TSL2561_INFRARED);
  luminosity = ambient.getFullLuminosity();

  infrared = luminosity >> 16;
  full = luminosity & 0xFFFF;
  visible = full - infrared;

  lux = ambient.calculateLux(full, infrared);

  // Scale battery percent with volts
  battery_percent = mapfloat(battery_volts, 1.8, 3.0, 0.0, 100.0);

#ifdef DEBUG
  Serial.print("Temperature: ");
  Serial.println(temp);
  Serial.print("Humidity: ");
  Serial.println(humidity);

  Serial.print("Pressure: ");
  Serial.print(pressure);
  Serial.println(" mbar");

  Serial.print("Temp2: ");
  Serial.print(temp2);
  Serial.println(" C");

  Serial.print("UV: ");
  Serial.println(uvIndex);

  Serial.print("Visible: ");
  Serial.println(visible);

  Serial.print("Full: ");
  Serial.println(full);

  Serial.print("Infrared: ");
  Serial.println(infrared);

  Serial.print("Lux: ");
  Serial.println(lux);

  Serial.print("Battery: ");
  Serial.println(battery_volts);

  Serial.print("Battery percent: ");
  Serial.println(battery_percent);
#endif

  Blynk.virtualWrite(1, temp);
  Blynk.virtualWrite(2, humidity);
  Blynk.virtualWrite(3, pressure);
  Blynk.virtualWrite(4, uvIndex);
  //Blynk.virtualWrite(5, full);
  Blynk.virtualWrite(6, infrared);
  //Blynk.virtualWrite(7, visible);
  Blynk.virtualWrite(8, lux);
  Blynk.virtualWrite(9, battery_volts);
  Blynk.virtualWrite(10, battery_percent);

  unsigned long lastMillis = millis();
  unsigned long took = (lastMillis-millisAtStart);

  Blynk.virtualWrite(11, took);

  Blynk.disconnect();

#ifdef DEBUG

  Serial.print("Took: ");
  Serial.print(took);
  Serial.print("ms");
  delay(100);
#endif

  // Shutdown immediately
  wl_shutdown();
}

void wl_shutdown() {
  digitalWrite(done_pin, HIGH);
}

float mapfloat(float x, float in_min, float in_max, float out_min, float out_max)
{
  return (x - in_min) * (out_max - out_min) / (in_max - in_min) + out_min;
}

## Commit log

2017-03-21 Some improvements during first manufacturing
    [board.kicad_pcb, board.sch]
2017-03-21 Resistor selection table updated
2017-04-05 Power consumption measurement images added
2017-04-23 Some improvements & 3D CAD files added
    [board.FCStd, board.kicad_pcb, board.sch]
2017-04-23 Gerber files updated
    [board-B.Cu.gbl, board-B.Mask.gbs, board-B.SilkS.gbo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]
2017-04-23 Deleted old gerber files
    [board-B.Cu.gbl, board-B.Mask.gbs, board-B.Paste.gbp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]
2017-05-17 Arduino IDE Config menu for programming added
